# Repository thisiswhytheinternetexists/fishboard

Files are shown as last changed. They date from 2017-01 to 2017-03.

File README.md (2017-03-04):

# FishBoard
## An Oak-Based controller for 12 Volts aquarium device control

Basic useful feature list:

- [ ] Switches LED strips on and off on a schedule or triggered by a REST call (REST call works, schedule is untested)
- [X] Allows up to 3 devices to be controlled (channel 1 and 2 work, todo: channel 3 troubleshooting)
- [ ] Manual override using buttons (doesn't currently work, todo: hardware troubleshooting)
- [X] Connects to your existing 2.4GHz WiFi Network for remote control and management (handled by the Oak Config, todo: write guide)
- [ ] Supports an SSD1306 OLED display for status and standalone operation
- [X] Integration with Domoticz (todo: write guide. Is a shell script that does a [particle API call](https://docs.particle.io/reference/firmware/photon/#particle-function-))

BOM:

| Manufacturer | P/N | Amount |
| --- | --- | --- |
| Multicomp | MJ-179PH | 1 |
| Fairchild | FQP30N06L | 3 |
| Multicomp | 1N5819 | 3 |
| WURTH Elektronik | 61300911121 | 2 |
| DigiStump | Oak | 1 |
| TE Connectivity | CFR16J10K | 1 | 
| Molex | 22-23-2021 | 7 |
| Molex | 22-01-2027 | 7 |
| Molex | 08-50-0032 | 14 |
| Multicomp | R13-24AL-05-BB | 4 |
| DELTRON ENCLOSURES | 479-0140-0 | 1 |
| Pro Power | PPW00030 | 2 |
 
Total BOM cost (excluding Oak and PCB) is roughly about EUR14.

Datasheet for MOSFET: http://www.mouser.com/ds/2/149/FQP30N06L-244344.pdf
Datasheet for enclosure: http://www.farnell.com/datasheets/1792140.pdf

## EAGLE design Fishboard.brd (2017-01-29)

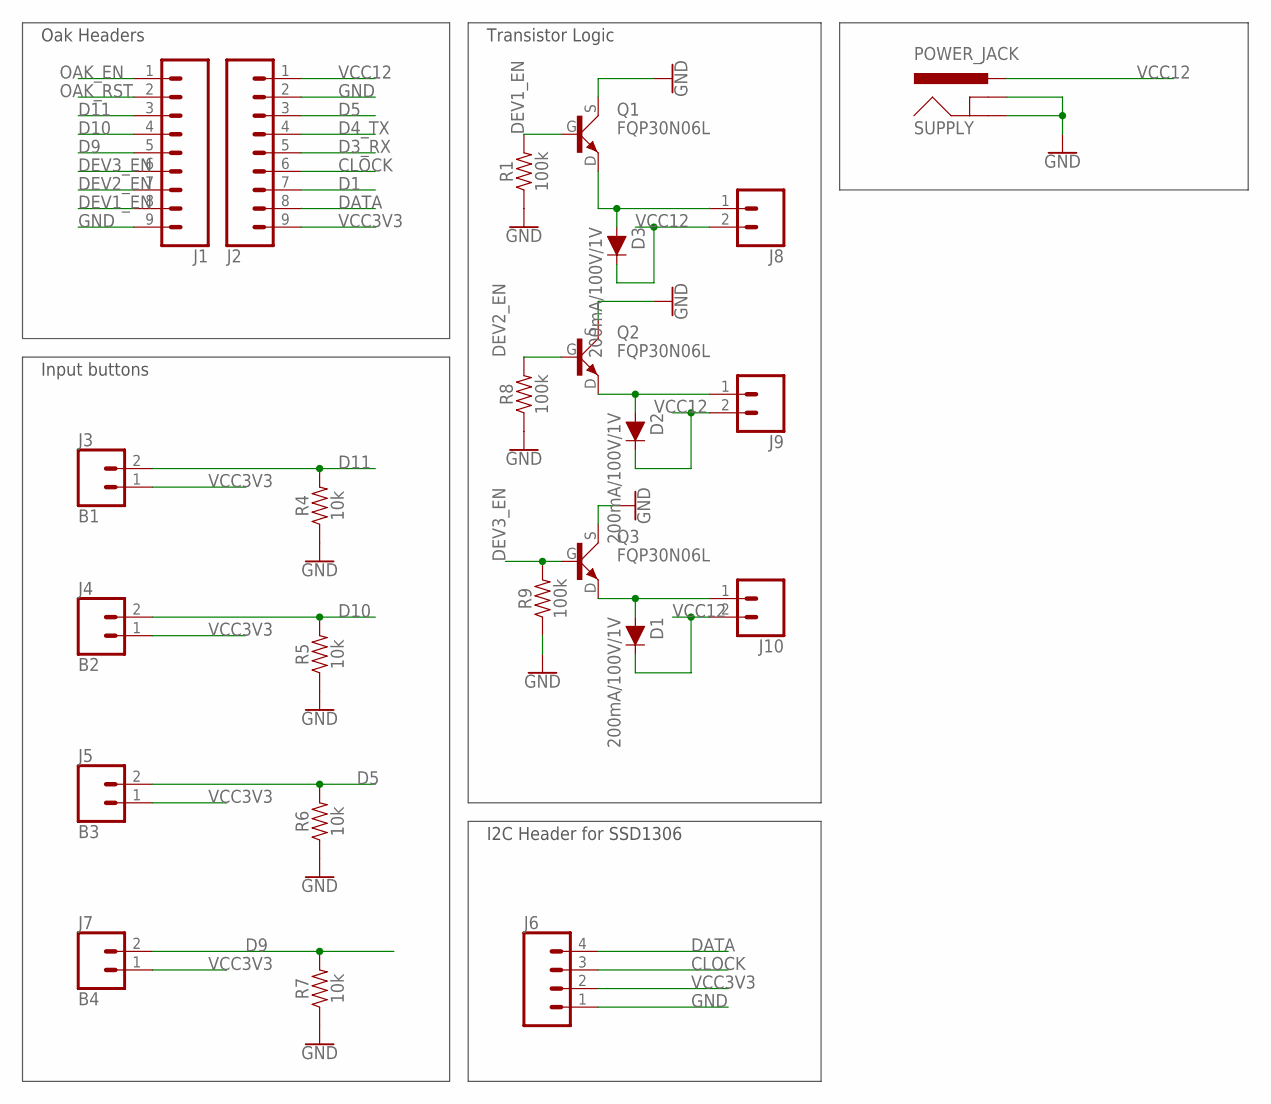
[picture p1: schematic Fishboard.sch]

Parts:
D1, D2, D3: 200mA/100V/1V; DIODE-1N4148-KIT
J1, J2: CONN_09LOCK; 1X09_LOCK
J3: B1; 1X02_LOCK
J4: B2; 1X02_LOCK
J5: B3; 1X02_LOCK
J6: CONN_04LOCK; 1X04_LOCK
J7: B4; 1X02_LOCK
J8, J9, J10: CONN_02PTH3; 1X02_LONGPADS
Q1, Q2, Q3: FQP30N06L; TO220
R1, R8, R9: 100k; AXIAL-0.3
R4, R5, R6, R7: 10k; AXIAL-0.3
SUPPLY: POWER_JACK; POWER_JACK_PTH

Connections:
CLOCK: J2.6, J6.3
D1: J2.7
D3_RX: J2.5
D4_TX: J2.4
D5: J2.3, J5.2, R6.P$2 (2)
D9: J1.5, J7.2, R7.P$2 (2)
D10: J1.4, J4.2, R5.P$2 (2)
D11: J1.3, J3.2, R4.P$2 (2)
DATA: J2.8, J6.4
DEV1_EN: J1.8, Q1.G (1), R1.P$2 (2)
DEV2_EN: J1.7, Q2.G (1), R8.P$2 (2)
DEV3_EN: J1.6, Q3.G (1), R9.P$2 (2)
GND: J1.9, J2.2, J6.1, Q1.S (3), Q2.S (3), Q3.S (3), R1.P$1 (1), R4.P$1 (1), R5.P$1 (1), R6.P$1 (1), R7.P$1 (1), R8.P$1 (1), R9.P$1 (1), SUPPLY.GND, SUPPLY.GNDBREAK
unnamed: D2.A, J9.1, Q2.D (2)
unnamed: D3.A, J8.1, Q1.D (2)
unnamed: D1.A, J10.1, Q3.D (2)
OAK_EN: J1.1
OAK_RST: J1.2
VCC3V3: J2.9, J3.1, J4.1, J5.1, J6.2, J7.1
VCC12: D1.C, D2.C, D3.C, J2.1, J8.2, J9.2, J10.2, SUPPLY.PWR

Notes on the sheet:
Oak Headers
Input buttons
I2C Header for SSD1306
Transistor Logic

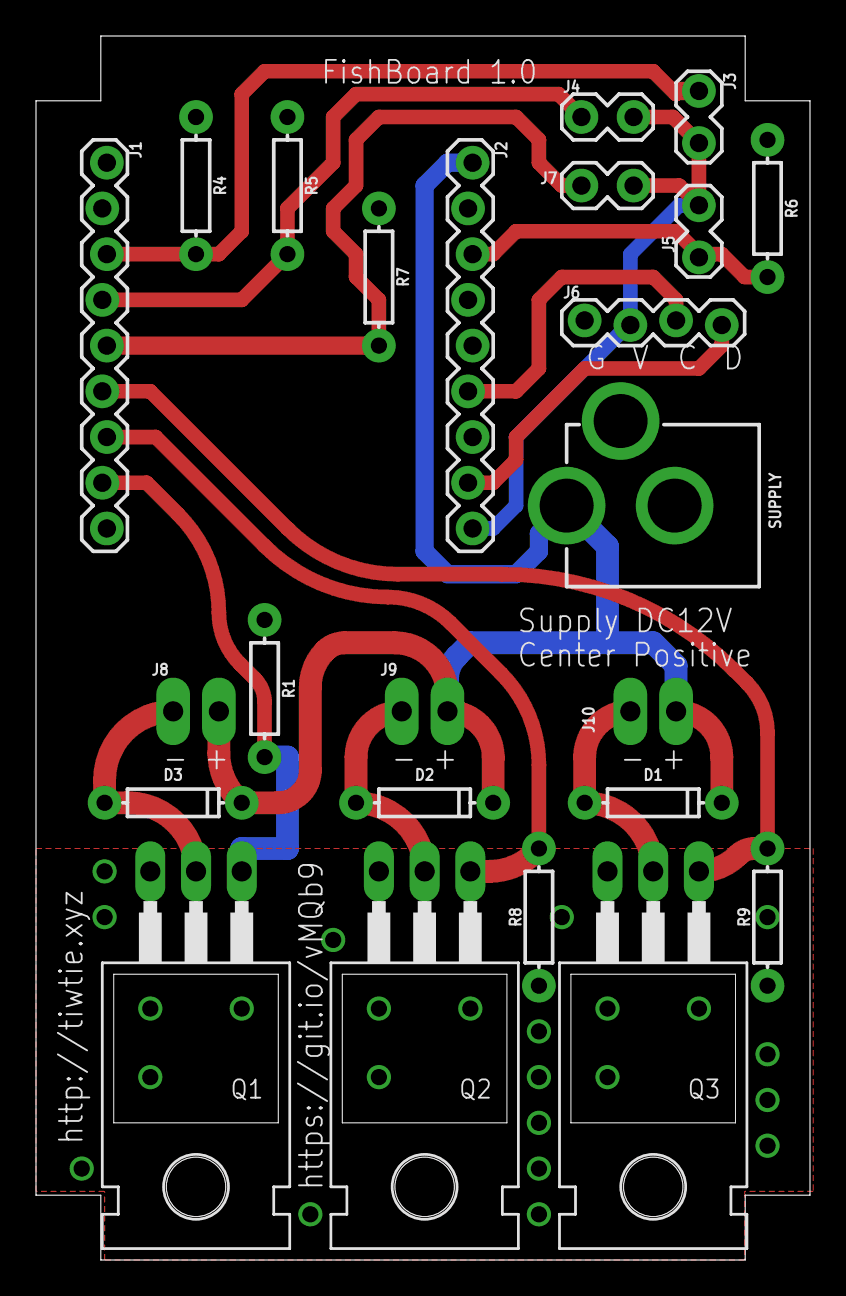
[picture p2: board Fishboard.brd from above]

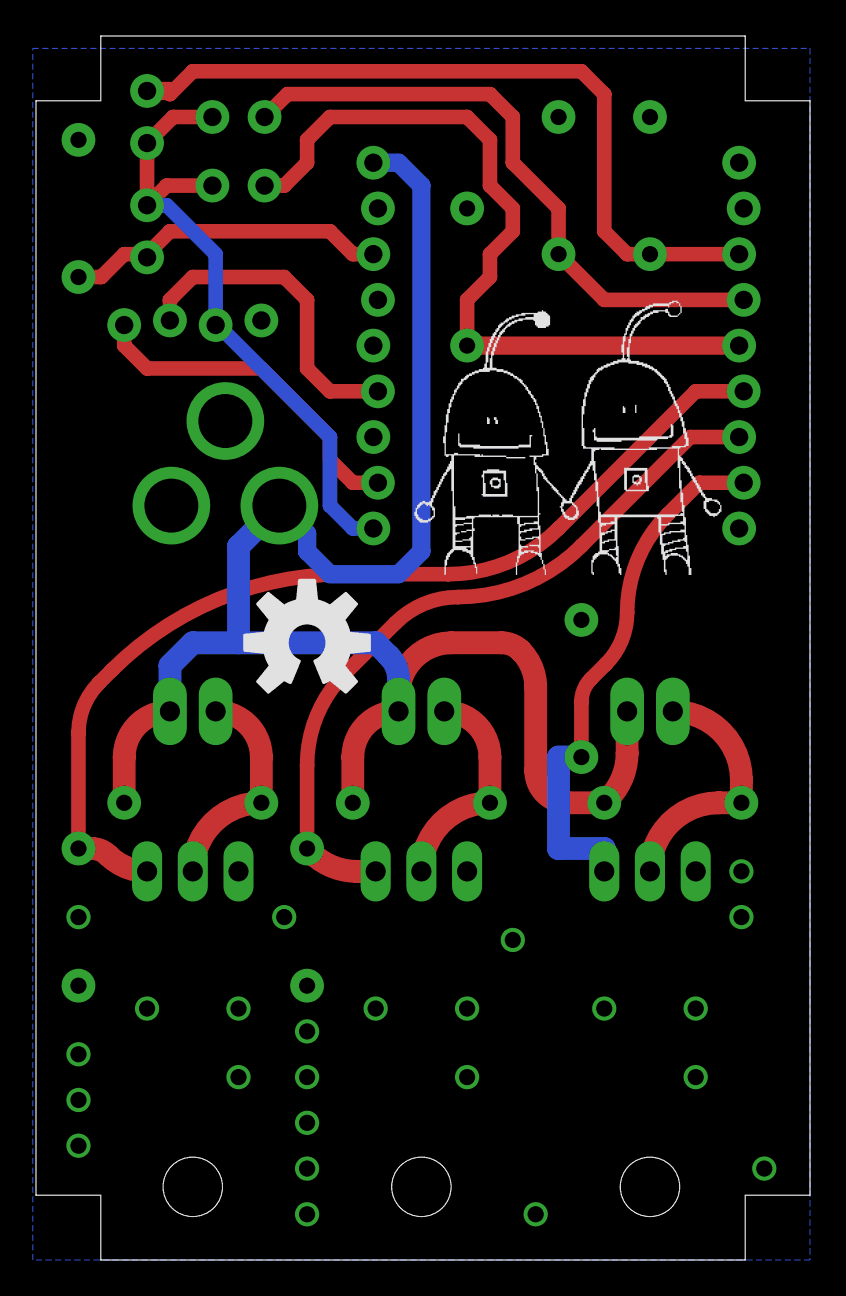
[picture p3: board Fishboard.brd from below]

Board: 2 copper layers, 43.0 x 68.0 mm, 26 parts (2 on the bottom side), 15 nets.

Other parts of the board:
U$1: TIWTIE_LOGO
U$2: OSHW-LOGO-L

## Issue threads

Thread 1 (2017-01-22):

Corrections to PCB/schematics

DJFliX, 2017-01-22:
- [ ] Add 330R resistors to Oak I/O pins ( http://www.g7smy.co.uk/2015/02/solenoids-on-the-arduino-with-mosfet-power/ )

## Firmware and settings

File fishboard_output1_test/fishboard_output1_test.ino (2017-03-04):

#include <Time.h>
#include <TimeLib.h>
#include <TimeAlarms.h>
#include <WiFiUdp.h>

IPAddress timeServer(94, 228, 220, 14); // time-a.timefreq.bldrdoc.gov
const int timeZone = 1;     // Central European Time
WiFiUDP Udp;
unsigned int localPort = 8888;  // local port to listen for UDP packets

int output_1_state = 0;
int output_2_state = 0;
int output_3_state = 0;

#define CHANNEL1_PIN 6
#define CHANNEL2_PIN 7
#define CHANNEL3_PIN 8

int SetChannel1State(String state);

void setup() {
  // put your setup code here, to run once:
  pinMode(CHANNEL1_PIN, OUTPUT);
  digitalWrite(CHANNEL1_PIN, LOW);
  pinMode(CHANNEL2_PIN, OUTPUT);
  digitalWrite(CHANNEL2_PIN, LOW);
  pinMode(CHANNEL3_PIN, OUTPUT);
  digitalWrite(CHANNEL3_PIN, LOW);
  
  Particle.function("ch1_state", SetChannel1State);
  Particle.function("ch2_state", SetChannel2State);
  Particle.function("ch3_state", SetChannel3State);
  
  Udp.begin(localPort);
  setSyncProvider(getNtpTime);
  Particle.publish("init_complete");

  while(timeStatus() == timeNotSet) {
    Particle.process();
    delay(10);
  }

  setTime(hour(),minute(),second(),day(),month(),year());
  
  //Alarm.alarmRepeat(07,00,00, Channel1On);
  //Alarm.alarmRepeat(17,00,00, Channel1Off);
  
}

int SetChannel1State(String state) {
  if(state == "true") Channel1On();
  else Channel1Off();
  return 1;
}

int SetChannel2State(String state) {
  if(state == "true") Channel2On();
  else Channel2Off();
  return 1;
}

int SetChannel3State(String state) {
  if(state == "true") Channel3On();
  else Channel3Off();
  return 1;
}

void loop() {
  Particle.process();
  Alarm.delay(50); 
}

void Channel1On(){
  output_1_state = 1;
  Particle.publish("ch1", "on");
  digitalWrite(CHANNEL1_PIN, HIGH);  
}

void Channel1Off(){
  output_1_state = 0;
  Particle.publish("ch1", "off");
  digitalWrite(CHANNEL1_PIN, LOW);           
}

void Channel2On(){
  output_2_state = 1;
  Particle.publish("ch2", "on");
  digitalWrite(CHANNEL2_PIN, HIGH);  
}

void Channel2Off(){
  output_2_state = 0;
  Particle.publish("ch2", "off");
  digitalWrite(CHANNEL2_PIN, LOW);           
}

void Channel3On(){
  output_3_state = 1;
  Particle.publish("ch3", "on");
  digitalWrite(CHANNEL3_PIN, HIGH);  
}

void Channel3Off(){
  output_3_state = 0;
  Particle.publish("ch3", "off");
  digitalWrite(CHANNEL3_PIN, LOW);           
}


const int NTP_PACKET_SIZE = 48; // NTP time is in the first 48 bytes of message
byte packetBuffer[NTP_PACKET_SIZE]; //buffer to hold incoming & outgoing packets

time_t getNtpTime()
{
  while (Udp.parsePacket() > 0) ; // discard any previously received packets
  Serial.println("Transmit NTP Request");
  sendNTPpacket(timeServer);
  uint32_t beginWait = millis();
  while (millis() - beginWait < 1500) {
    int size = Udp.parsePacket();
    if (size >= NTP_PACKET_SIZE) {
      Serial.println("Receive NTP Response");
      Udp.read(packetBuffer, NTP_PACKET_SIZE);  // read packet into the buffer
      unsigned long secsSince1900;
      // convert four bytes starting at location 40 to a long integer
      secsSince1900 =  (unsigned long)packetBuffer[40] << 24;
      secsSince1900 |= (unsigned long)packetBuffer[41] << 16;
      secsSince1900 |= (unsigned long)packetBuffer[42] << 8;
      secsSince1900 |= (unsigned long)packetBuffer[43];
      return secsSince1900 - 2208988800UL + timeZone * SECS_PER_HOUR;
    }
  }
  Serial.println("No NTP Response :-(");
  return 0; // return 0 if unable to get the time
}

// send an NTP request to the time server at the given address
void sendNTPpacket(IPAddress &address)
{
  // set all bytes in the buffer to 0
  memset(packetBuffer, 0, NTP_PACKET_SIZE);
  // Initialize values needed to form NTP request
  // (see URL above for details on the packets)
  packetBuffer[0] = 0b11100011;   // LI, Version, Mode
  packetBuffer[1] = 0;     // Stratum, or type of clock
  packetBuffer[2] = 6;     // Polling Interval
  packetBuffer[3] = 0xEC;  // Peer Clock Precision
  // 8 bytes of zero for Root Delay & Root Dispersion
  packetBuffer[12]  = 49;
  packetBuffer[13]  = 0x4E;
  packetBuffer[14]  = 49;
  packetBuffer[15]  = 52;
  // all NTP fields have been given values, now
  // you can send a packet requesting a timestamp:                 
  Udp.beginPacket(address, 123); //NTP requests are to port 123
  Udp.write(packetBuffer, NTP_PACKET_SIZE);
  Udp.endPacket();
}

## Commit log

2017-01-22 Initial commit. I'll have this reviewed by someone before sending it off to the fab :)
    [Fishboard.brd, Fishboard.sch]
2017-01-22 Reorganized schematics
    [Fishboard.brd, Fishboard.sch]
2017-01-22 Switched the TIP120 with a logic level MOSFET (FQP30N06L). The current limiting resistors have been replaced with pulldowns.
    [Fishboard.brd, Fishboard.sch]
2017-01-22 Replaced TIP120 part with custom part so that we can correctly route it.
    [Fishboard.brd, Fishboard.sch]
2017-01-22 Added reference to MOSFET datasheet in README.md
2017-01-29 Moved Open Source Hardware logo to bottom of board. Added flyback diodes.
    [Fishboard.brd, Fishboard.sch]
2017-01-29 Changed the board size and rerouted everything to make the board fit the case I selected
    [Fishboard.brd]
2017-01-29 Update readme to include BOM
2017-01-29 Change the net for the gndplane-connecting vias to GND. Renamed a FET to Q3 instead of U$3.
    [Fishboard.brd, Fishboard.sch]
2017-02-11 I've tested the board with an arduino sketch. And it works! #awesome. Placed an order for 3x the PCB to see if that will work as well!
2017-03-04 Reformat readme BOM table
2017-03-04 Updated readme to reflect current state of the project

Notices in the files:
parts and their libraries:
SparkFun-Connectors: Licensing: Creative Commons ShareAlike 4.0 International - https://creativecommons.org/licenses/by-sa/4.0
